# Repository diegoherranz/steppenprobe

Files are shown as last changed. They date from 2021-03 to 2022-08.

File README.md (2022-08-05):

# Steppenprobe
Open Source Hardware JTAG/SWD/UART/SWO interface board

https://github.com/diegoherranz/steppenprobe

## Basic specs:

- Open Source Hardware and designed in [KiCad](https://kicad.org).
- [FT2232H](https://ftdichip.com/products/ft2232hl)-based
- Simultaneous operation of JTAG/SWD and UART/SWO.
- STDC14 connector: standard Arm Cortex debug connector (1.27 mm pitch) with extra pins for UART. JTAG/SWD and UART on a single connector while being compatible with the standard Arm Cortex debug connector (middle 10 pins).
- USB powered: no power supply needed.
- USB type-C receptacle: more convenient (reversible) and future-proof (it should be the most common connector during the next few years).
- OpenOCD compatible, supported from version 0.11.0 (older versions can be used by adapting this [config file](https://sourceforge.net/p/openocd/code/ci/master/tree/tcl/interface/ftdi/steppenprobe.cfg) to the old sintax).
- JTAG or SWD use without any jumper or switch operation required (configured from OpenOCD).
- Switch-selectable UART RX or SWO operation.
- Signals also available on 2.54 mm pin header to work with any custom pinout.
- 4 GPIO.
- System Reset tactile switch.
- I/O buffers for protection and to be able to use a wide voltage range (1.65 V to 5.5 V).
- Descriptive LED indicators.

## Schematic PDF, Gerbers and other generated files:
See [releases](https://github.com/diegoherranz/steppenprobe/releases).

## FTDI channels

The FT2232H has 2 independent channels. In this board:

- Channel A: Used for JTAG or SWD (MPSSE mode) + GPIOs
- Channel B: Used as UART. TX+RX or TX+SWO depending on the position of the physical switch.

After enumeration, both channels will default to UART mode, so on a Linux system they will show up as `/dev/ttyUSB0` and `/dev/ttyUSB1`. When channel A gets reconfigured to MPSSE mode (e.g. when using OpenOCD with it), then `/dev/ttyUSB0` will disappear and channel B will remain as `/dev/ttyUSB1`.

## 3D renders

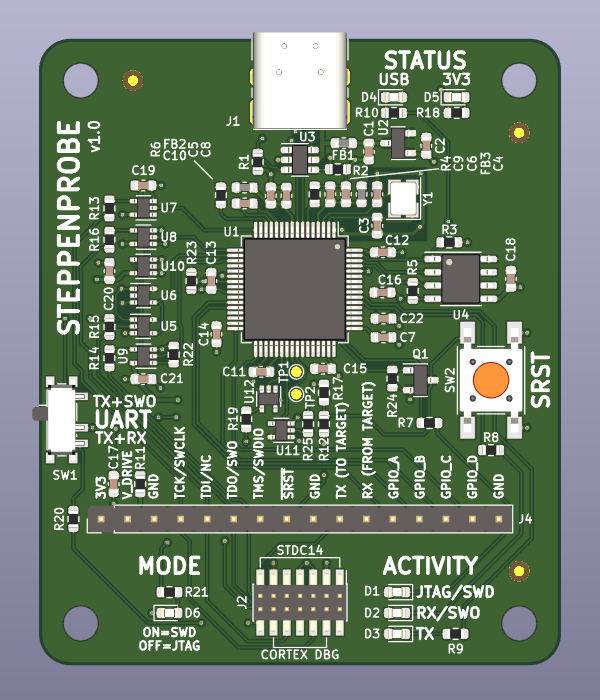
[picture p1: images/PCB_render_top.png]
PCB top view
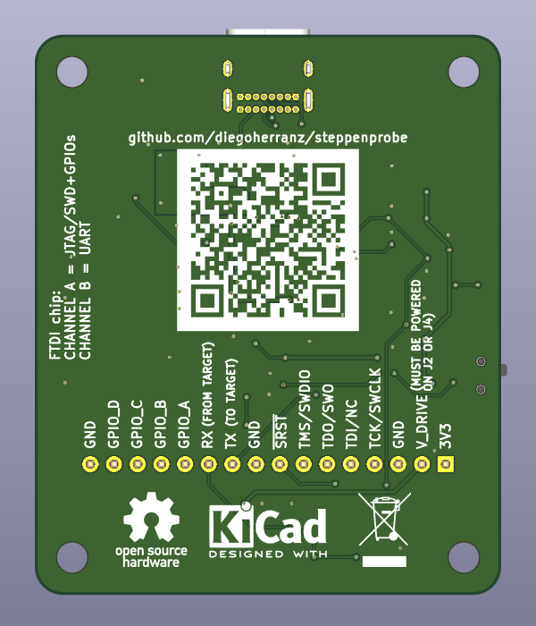
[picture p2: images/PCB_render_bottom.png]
PCB bottom view
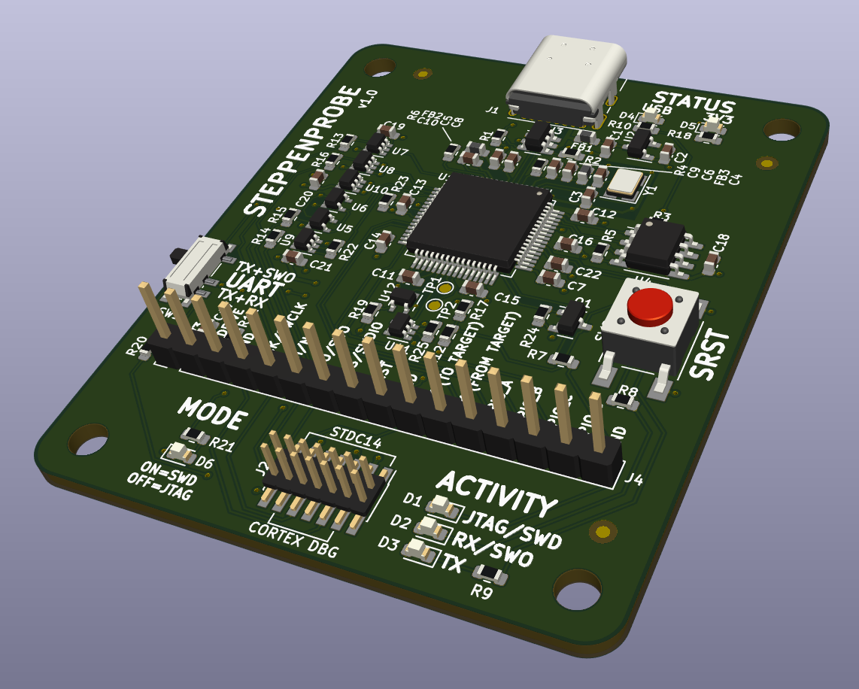
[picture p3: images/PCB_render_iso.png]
PCB isometric view
  

## Options for J2 connector (1.27 mm pitch header)
You can solder a 10-way or 14-way header depending on what suits you best:
 - 10-way header: [FTSH-105-01-F-DV-K](https://www.samtec.com/products/ftsh-105-01-f-dv-k) or equivalent. Use the central 10 pads in this case. JTAG, SWD, SWO and RESET (Arm Cortex debug connector standard).
 - 14-way header: [FTSH-107-01-F-DV-K](https://www.samtec.com/products/ftsh-107-01-f-dv-k) or equivalent. Compared to the 10 pin option, it adds UART TX and RX (STDC14 standard). This can still connect to targets with a 10-way header by using a 14-way to 10-way cable.

## OpenOCD example commands

### Flashing
Flashing [NuttX](https://nuttx.apache.org) to a [Blue Pill](https://stm32-base.org/boards/STM32F103C8T6-Blue-Pill.html) using JTAG:

```
openocd -f interface/ftdi/steppenprobe.cfg -f target/stm32f1x.cfg -c "program nuttx.bin 0x08000000 verify reset exit"
```

Same but using SWD:

```
openocd -f interface/ftdi/steppenprobe.cfg -c "transport select swd" -f target/stm32f1x.cfg -c "program nuttx.bin 0x08000000 verify reset exit"
```
All these examples use the default reset signals configuration. You may need to adjust it for your target board to work or even if it works, you may want to define it explicitely. See the [Reset Configuration chapter](http://openocd.org/doc-release/html/Reset-Configuration.html) of the OpenOCD documentation for more details.

You can do so directly on the OpenOCD command:

```
openocd -f interface/ftdi/steppenprobe.cfg -c "reset_config srst_only" -f target/stm32f1x.cfg -c "program nuttx.bin 0x08000000 verify reset exit"
```

or defining your board config file (your_board.cfg) which may look like this:

```
reset_config srst_only
source [find target/stm32f4x.cfg]
```

And then you do:

```
openocd -f interface/ftdi/steppenprobe.cfg -f your_board.cfg -c "program nuttx.bin 0x08000000 verify reset exit"
```

### Debugging
Debugging example for an STM32F4 target.

Start OpenOCD:
- JTAG: `openocd -f interface/ftdi/steppenprobe.cfg -f target/stm32f4x.cfg`
- SWD: `openocd -f interface/ftdi/steppenprobe.cfg -c "transport select swd" -f target/stm32f4x.cfg
`

On a different terminal:
```
$ gdb-multiarch your_code.elf # or gcc-arm-none-eabi depending on your system.

# Attach to OpenOCD
(gdb) target extended-remote localhost:3333

# Reset the boad
(gdb) monitor reset halt

# Load the code to flash
(gdb) load

# Start running
continue
```
Then use GDB as normal: see https://www.gnu.org/software/gdb/documentation/

### Debugging + SWO

Start OpenOCD in SWD mode and use the `tpiu config` command. Also, the UART switch should be in the "TX+SWO" position.

```
openocd -f interface/ftdi/steppenprobe.cfg -c "transport select swd" -f target/stm32f4x.cfg -c "tpiu config external uart off 168000000 115200"
```

The `tpiu config` command configures the ARM ITM module and the SWO output. In the command above, `16800000` represents the TRACECLKIN frequency (usually the same as HCLK), and `115200` is the frequency/baurate of the SWO line. Adjust both as desired. See the [OpenOCD documentation](http://openocd.org/doc-release/html/Architecture-and-Core-Commands.html#ARMv7_002dM-specific-commands
) for more info.

If the selected SWO frequency can't be achieved, OpenOCD will output a message like:

> Info : Can not obtain 115200 trace port frequency from 168000000 TRACECLKIN frequency, using 115147 instead

In this case, the frequency achieved is close enough, but pay attention in case it wasn't.

Then, on another terminal:
```
# configure the serial port speed
stty -F /dev/ttyUSB1 115200

# start the ITM decoder
./itmdump -f /dev/ttyUSB1 -d1 
```

Note: ITM decoder available [here](https://sourceforge.net/p/openocd/code/ci/master/tree/contrib/itmdump.c), just compile by doing `gcc itmdump.c -o itmdump`.

One of the advantages of using the SWO signal is that it can be faster than a standard UART, specially for slow core clock frequencies (see [this nice article](https://blog.japaric.io/itm/) for more info). To benefit from that, we need to use faster SWO frequencies.

The FT2232H is capable or running the UART up to 12 Mbps, but the configuration is more cumbersome for the fastest speeds.

On a recent Linux system, you can go up to 4 Mbps, configuring everything the same way as explained above for 115200 bps. On different OSes, you may not be able to go above 115200 bps or even 38400 bps.

For 4 Mbps:

```
openocd -f interface/ftdi/steppenprobe.cfg -c "transport select swd" -f target/stm32f4x.cfg -c "tpiu config external uart off 168000000 4000000"
```

On another terminal:
```
stty -F /dev/ttyUSB1 4000000
./itmdump -f /dev/ttyUSB1 -d1
```

To use even higher frequencies, up to the maximum of 12 MHz if your setup and cabling allows it, it's necessary to use setserial to alias 38400 bps to a custom divider. The base frequency of the FT2232H is 60 MHz, so for instance, for 12 MHz, the divisor must be set to 5.

```
openocd -f interface/ftdi/steppenprobe.cfg -c "transport select swd" -f target/stm32f4x.cfg -c "tpiu config external uart off 168000000 12000000"
```

On a different terminal:
```
setserial /dev/ttyUSB1 spd_cust divisor 5
stty -F /dev/ttyUSB1 38400
./itmdump -f /dev/ttyUSB1 -d1
```

### GPIO usage
There are 4 GPIOs available: GPIO_A to GPIO_D. By default they are High-Impedance (Z).

They can be set through OpenOCD by using `ftdi_set_signal name 0|1|z`. For example:
```
ftdi_set_signal GPIO_B 1
```

And similarly, they can be read using `ftdi_get_signal name`.

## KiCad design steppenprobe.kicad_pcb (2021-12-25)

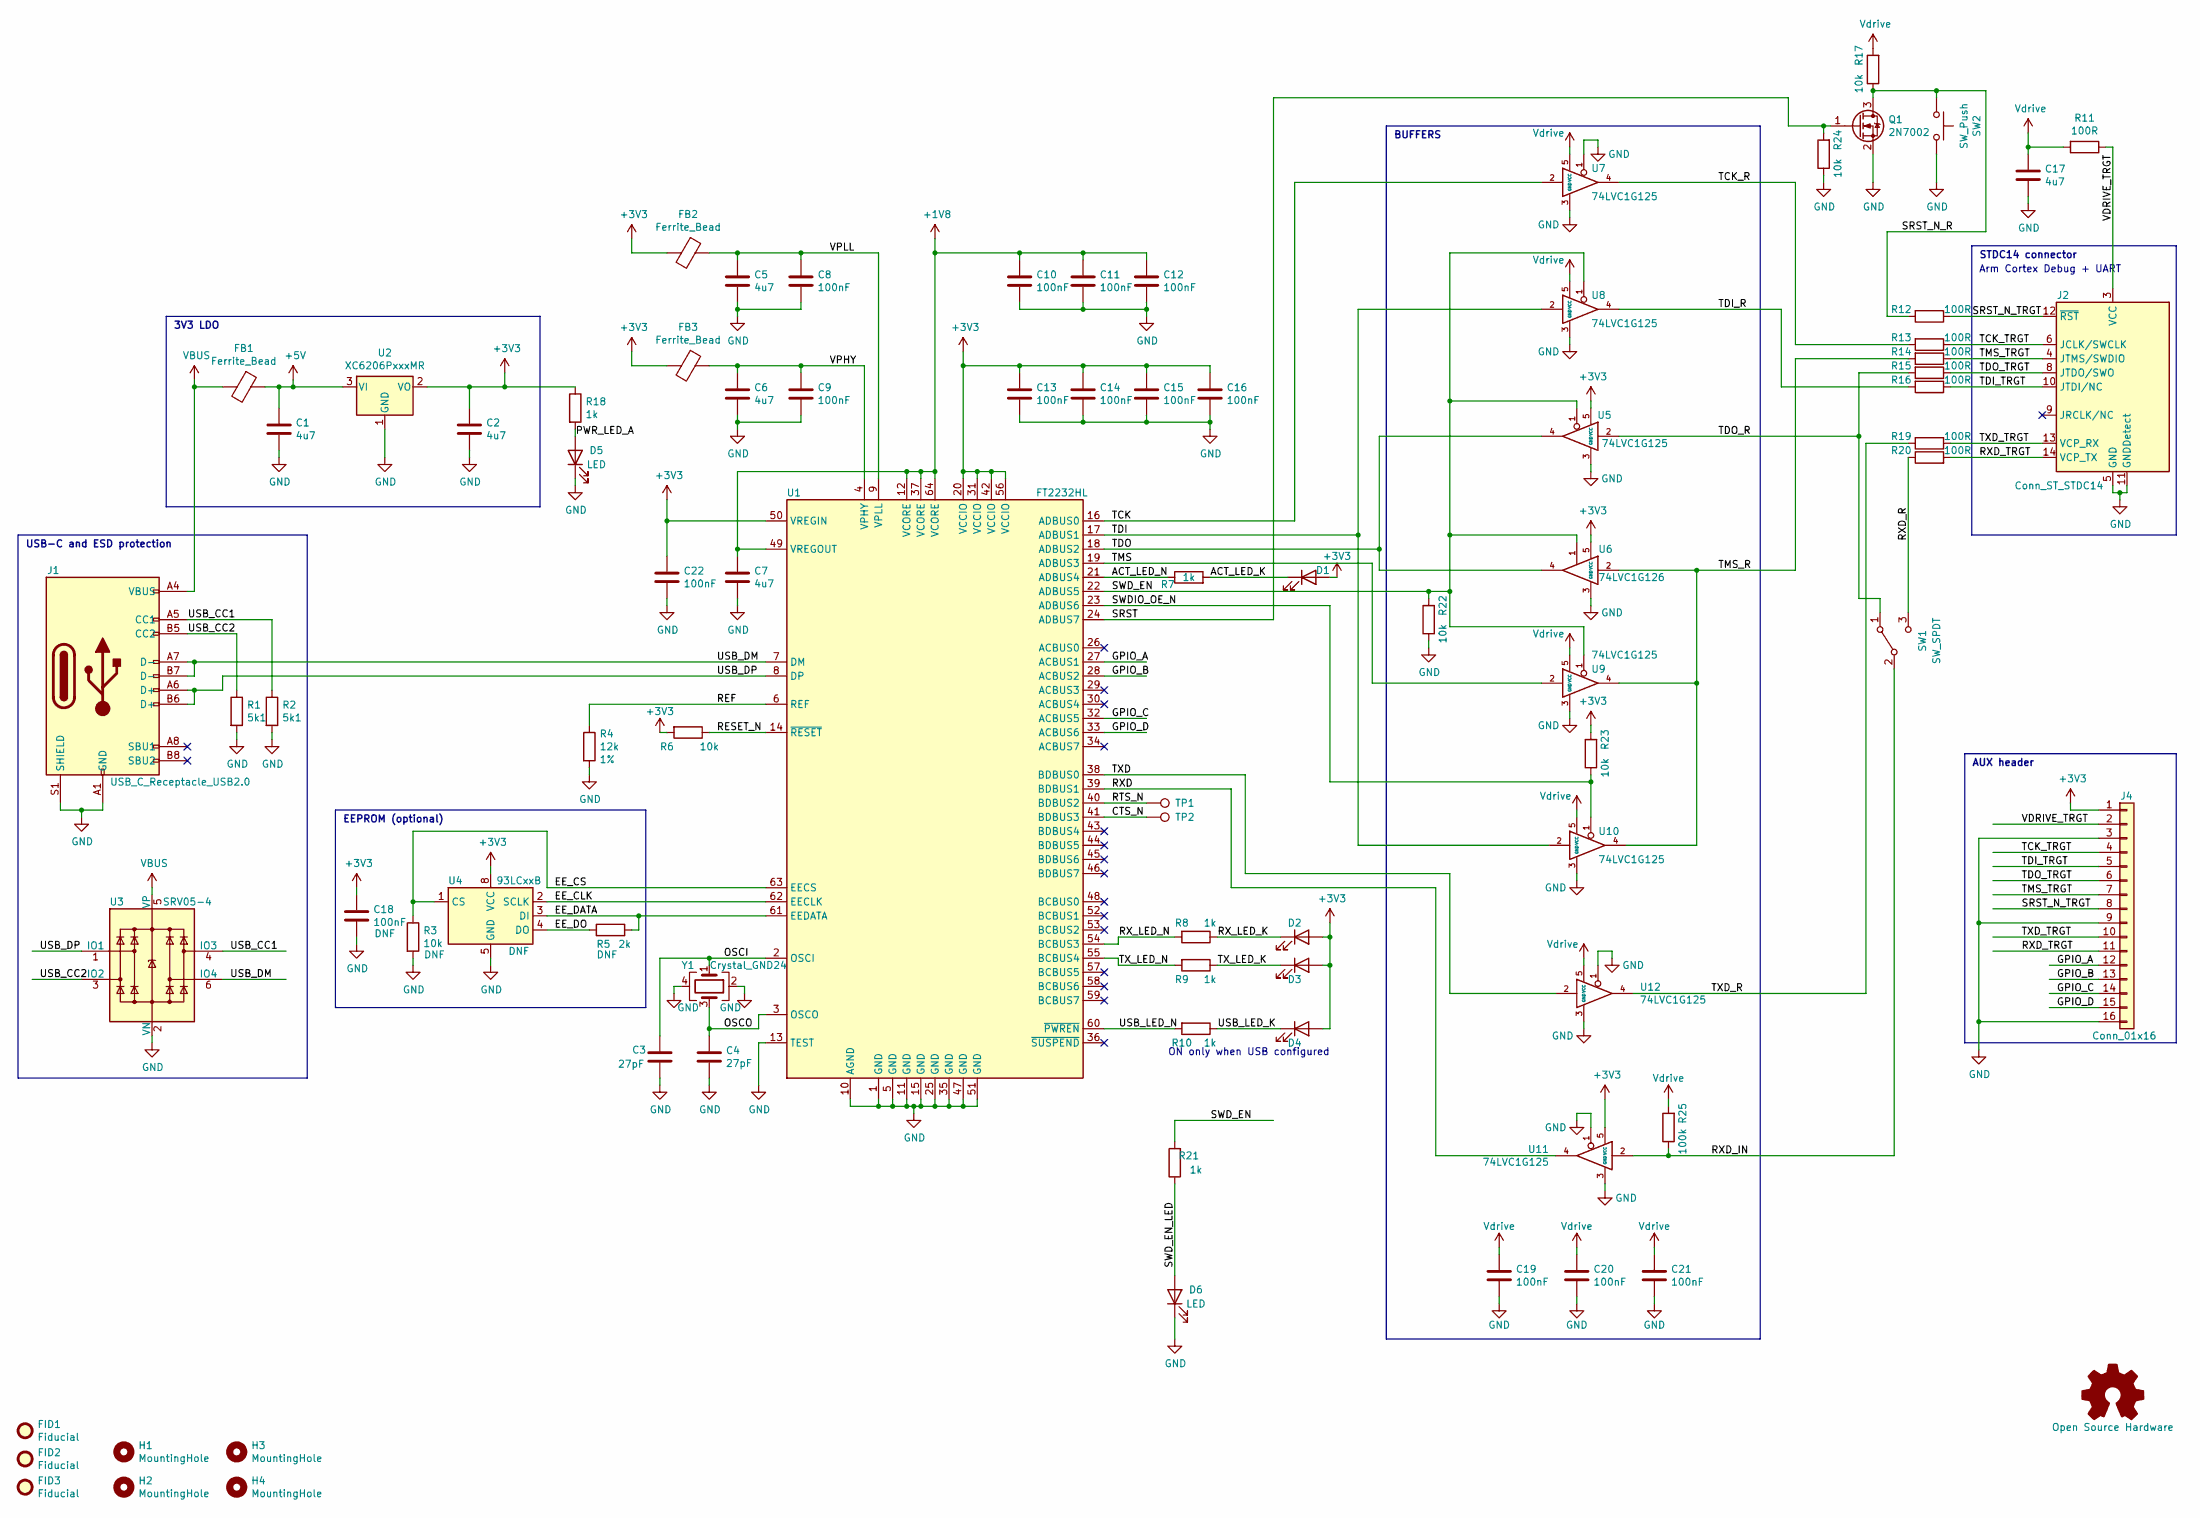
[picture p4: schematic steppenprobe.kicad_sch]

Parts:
C1, C2, C5, C6, C7, C17: 4u7; C_0603_1608Metric; Tolerance 10%; MPN CL10A475KO8NNNC; LCSC_PN C19666
C3, C4: 27pF; C_0603_1608Metric; Tolerance 5%; MPN C0603C270J5GAC; LCSC_PN C1656
C8, C9, C10, C11, C12, C13, C14, C15, C16, C19, C20, C21, C22: 100nF; C_0603_1608Metric; Tolerance 10%; MPN CC0603KRX7R9BB104; LCSC_PN C14663
C18: 100nF; C_0603_1608Metric
D1, D2, D3, D4, D5, D6: LED; LED_0603_1608Metric; MPN 19-217/GHC-YR1S2/3T; LCSC_PN C72043
FB1, FB2, FB3: Ferrite_Bead; L_0603_1608Metric; MPN2 BKP1608HS121-T; LCSC_PN C85831
FID1, FID2, FID3: Fiducial; Fiducial_1mm_Mask2mm
H1, H2, H3, H4: MountingHole; MountingHole_3.2mm_M3
J1: USB_C_Receptacle_USB2.0; USB_C_Receptacle_GCT_USB4085; MPN USB4085-GF-A
J2: Conn_ST_STDC14; PinHeader_2x07_P1.27mm_Vertical_SMD; MPN FTSH-107-01-F-DV-K (if 14-way)
J4: Conn_01x16; PinHeader_1x16_P2.54mm_Vertical; MPN M20-9991645
LOGO1: Open Source Hardware; OSHW-Logo_7.5x8mm_SilkScreen
Q1: 2N7002; SOT-23; MPN 2N7002-7-F; LCSC_PN C8545
R1, R2: 5k1; R_0603_1608Metric; Tolerance 5%; LCSC_PN C23186
R3: 10k; R_0603_1608Metric
R4: 12k; R_0603_1608Metric; Tolerance 1%; LCSC_PN C22790
R5: 2k; R_0603_1608Metric
R6, R17, R22, R23, R24: 10k; R_0603_1608Metric; Tolerance 5%; LCSC_PN C25804
R7, R8, R9, R10, R18, R21: 1k; R_0603_1608Metric; Tolerance 5%; LCSC_PN C21190
R11, R12, R13, R14, R15, R16, R19, R20: 100R; R_0603_1608Metric; Tolerance 5%; LCSC_PN C22775
R25: 100k; R_0603_1608Metric; Tolerance 5%; LCSC_PN C25803
SW1: SW_SPDT; SW_SPDT_PCM12; MPN EG1215AA
SW2: SW_Push; SW_Push_1P1T_NO_E-Switch_TL3301NxxxxxG; MPN PTS645SK43SMTR92 LFS
TP1, TP2: TestPoint; TestPoint_Pad_D1.0mm
U1: FT2232HL; LQFP-64_10x10mm_P0.5mm; MPN FT2232HL; LCSC_PN C27882
U2: XC6206PxxxMR; SOT-23; MPN XC6206P332MR; LCSC_PN C5446
U3: SRV05-4; SOT-23-6; MPN2 SRV05-4-P-T7; LCSC_PN C85364
U4: 93LCxxB; SOIC-8_3.9x4.9mm_P1.27mm
U5, U7, U8, U9, U10, U11, U12: 74LVC1G125; SOT-353_SC-70-5; MPN 74LVC1G125GW,125; LCSC_PN C12519
U6: 74LVC1G126; SOT-353_SC-70-5; MPN 74LVC1G126GW,125; LCSC_PN C55052
Y1: Crystal_GND24; Crystal_SMD_3225-4Pin_3.2x2.5mm; Tolerance 10PPM; MPN ABM8-12.000MHZ-20-B1U-T; LCSC_PN C9002

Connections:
+1V8: C7.1, C10.1, C11.1, C12.1, U1.12 (VCORE), U1.37 (VCORE), U1.49 (VREGOUT), U1.64 (VCORE)
+3V3: C2.1, C13.1, C14.1, C15.1, C16.1, C18.1, C22.1, D1.2 (A), D2.2 (A), D3.2 (A), D4.2 (A), FB2.2, FB3.2, J4.1, R6.2, R18.1, R23.2, U1.20 (VCCIO), U1.31 (VCCIO), U1.42 (VCCIO), U1.50 (VREGIN), U1.56 (VCCIO), U2.2 (VO), U4.8 (VCC), U5.5 (VCC), U6.5 (VCC), U11.5 (VCC)
+5V: C1.1, FB1.1, U2.3 (VI)
/ACT_LED_K: D1.1 (K), R7.2
/ACT_LED_N: R7.1, U1.21 (ADBUS4)
/CTS_N: TP2.1, U1.41 (BDBUS3)
/EE_CLK: U1.62 (EECLK), U4.2 (SCLK)
/EE_CS: R3.1, U1.63 (EECS), U4.1 (CS)
/EE_DATA: R5.2, U1.61 (EEDATA), U4.3 (DI)
/EE_DO: R5.1, U4.4 (DO)
/GPIO_A: J4.12, U1.27 (ACBUS1)
/GPIO_B: J4.13, U1.28 (ACBUS2)
/GPIO_C: J4.14, U1.32 (ACBUS5)
/GPIO_D: J4.15, U1.33 (ACBUS6)
/OSCI: C3.1, U1.2 (OSCI), Y1.1
/OSCO: C4.1, U1.3 (OSCO), Y1.3
/PWR_LED_A: D5.2 (A), R18.2
/REF: R4.1, U1.6 (REF)
/RESET_N: R6.1, U1.14 (~RESET)
/RTS_N: TP1.1, U1.40 (BDBUS2)
/RXD: U1.39 (BDBUS1), U11.4
/RXD_IN: R25.1, SW1.2 (B), U11.2
/RXD_R: R20.1, SW1.3 (C)
/RXD_TRGT: J2.14 (VCP_TX), J4.11, R20.2
/RX_LED_K: D2.1 (K), R8.1
/RX_LED_N: R8.2, U1.54 (BCBUS3)
/SRST: Q1.1 (G), R24.2, U1.24 (ADBUS7)
/SRST_N_R: Q1.3 (D), R12.2, R17.1, SW2.1
/SRST_N_TRGT: J2.12 (~RST), J4.8, R12.1
/SWDIO_OE_N: R23.1, U1.23 (ADBUS6), U10.1
/SWD_EN: R21.2, R22.2, U1.22 (ADBUS5), U5.1, U6.1, U8.1, U9.1
/SWD_EN_LED: D6.2 (A), R21.1
/TCK: U1.16 (ADBUS0), U7.2
/TCK_R: R13.2, U7.4
/TCK_TRGT: J2.6 (JCLK/SWCLK), J4.4, R13.1
/TDI: U1.17 (ADBUS1), U8.2, U10.2
/TDI_R: R16.2, U8.4
/TDI_TRGT: J2.10 (JTDI/NC), J4.5, R16.1
/TDO: U1.18 (ADBUS2), U5.4, U6.4
/TDO_R: R15.2, SW1.1 (A), U5.2
/TDO_TRGT: J2.8 (JTDO/SWO), J4.6, R15.1
/TMS: U1.19 (ADBUS3), U9.2
/TMS_R: R14.2, U6.2, U9.4, U10.4
/TMS_TRGT: J2.4 (JTMS/SWDIO), J4.7, R14.1
/TXD: U1.38 (BDBUS0), U12.2
/TXD_R: R19.2, U12.4
/TXD_TRGT: J2.13 (VCP_RX), J4.10, R19.1
/TX_LED_K: D3.1 (K), R9.1
/TX_LED_N: R9.2, U1.55 (BCBUS4)
/USB_CC1: J1.A5 (CC1), R2.1, U3.4 (IO3)
/USB_CC2: J1.B5 (CC2), R1.1, U3.3 (IO2)
/USB_DM: J1.A7 (D-), J1.B7 (D-), U1.7 (DM), U3.6 (IO4)
/USB_DP: J1.A6 (D+), J1.B6 (D+), U1.8 (DP), U3.1 (IO1)
/USB_LED_K: D4.1 (K), R10.1
/USB_LED_N: R10.2, U1.60 (~PWREN)
/VDRIVE_TRGT: J2.3 (VCC), J4.2, R11.1
/VPHY: C6.1, C9.1, FB3.1, U1.4 (VPHY)
/VPLL: C5.1, C8.1, FB2.1, U1.9 (VPLL)
GND: C1.2, C2.2, C3.2, C4.2, C5.2, C6.2, C7.2, C8.2, C9.2, C10.2, C11.2, C12.2, C13.2, C14.2, C15.2, C16.2, C17.2, C18.2, C19.2, C20.2, C21.2, C22.2, D5.1 (K), D6.1 (K), J1.A1 (GND), J1.A12 (GND), J1.B1 (GND), J1.B12 (GND), J1.S1 (SHIELD), J2.5 (GND), J2.7 (GND), J2.11 (GNDDetect), J4.3, J4.9, J4.16, Q1.2 (S), R1.2, R2.2, R3.2, R4.2, R22.1, R24.1, SW2.2, U1.1 (GND), U1.5 (GND), U1.10 (AGND), U1.11 (GND), U1.13 (TEST), U1.15 (GND), U1.25 (GND), U1.35 (GND), U1.47 (GND), U1.51 (GND), U2.1 (GND), U3.2 (VN), U4.5 (GND), U5.3 (GND), U6.3 (GND), U7.1, U7.3 (GND), U8.3 (GND), U9.3 (GND), U10.3 (GND), U11.1, U11.3 (GND), U12.1, U12.3 (GND), Y1.2, Y1.4
VBUS: FB1.2, J1.A4 (VBUS), J1.A9 (VBUS), J1.B4 (VBUS), J1.B9 (VBUS), U3.5 (VP)
Vdrive: C17.1, C19.1, C20.1, C21.1, R11.2, R17.2, R25.2, U7.5 (VCC), U8.5 (VCC), U9.5 (VCC), U10.5 (VCC), U12.5 (VCC)

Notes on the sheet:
EEPROM (optional)
ON only when USB configured
Arm Cortex Debug + UART
3V3 LDO
AUX header
STDC14 connector
USB-C and ESD protection
BUFFERS

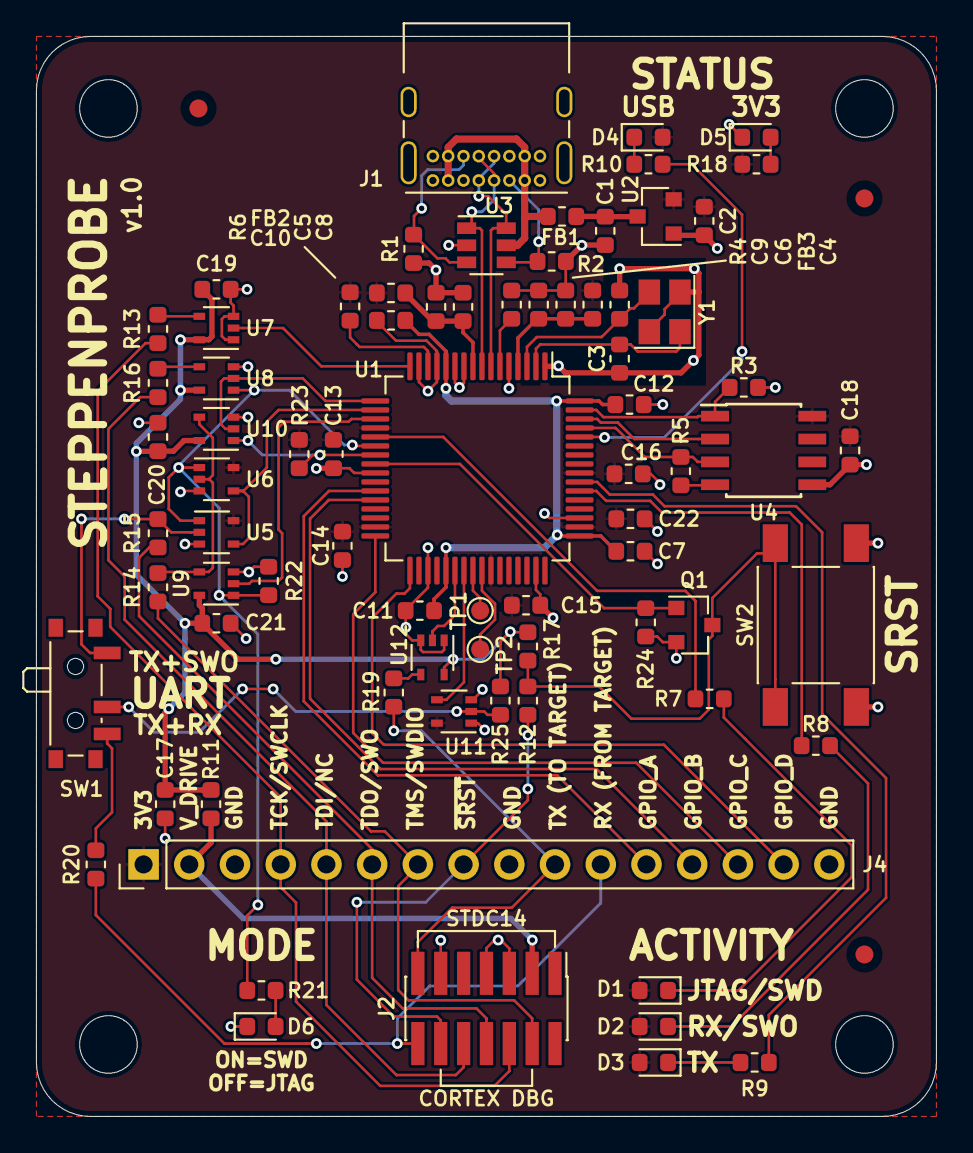
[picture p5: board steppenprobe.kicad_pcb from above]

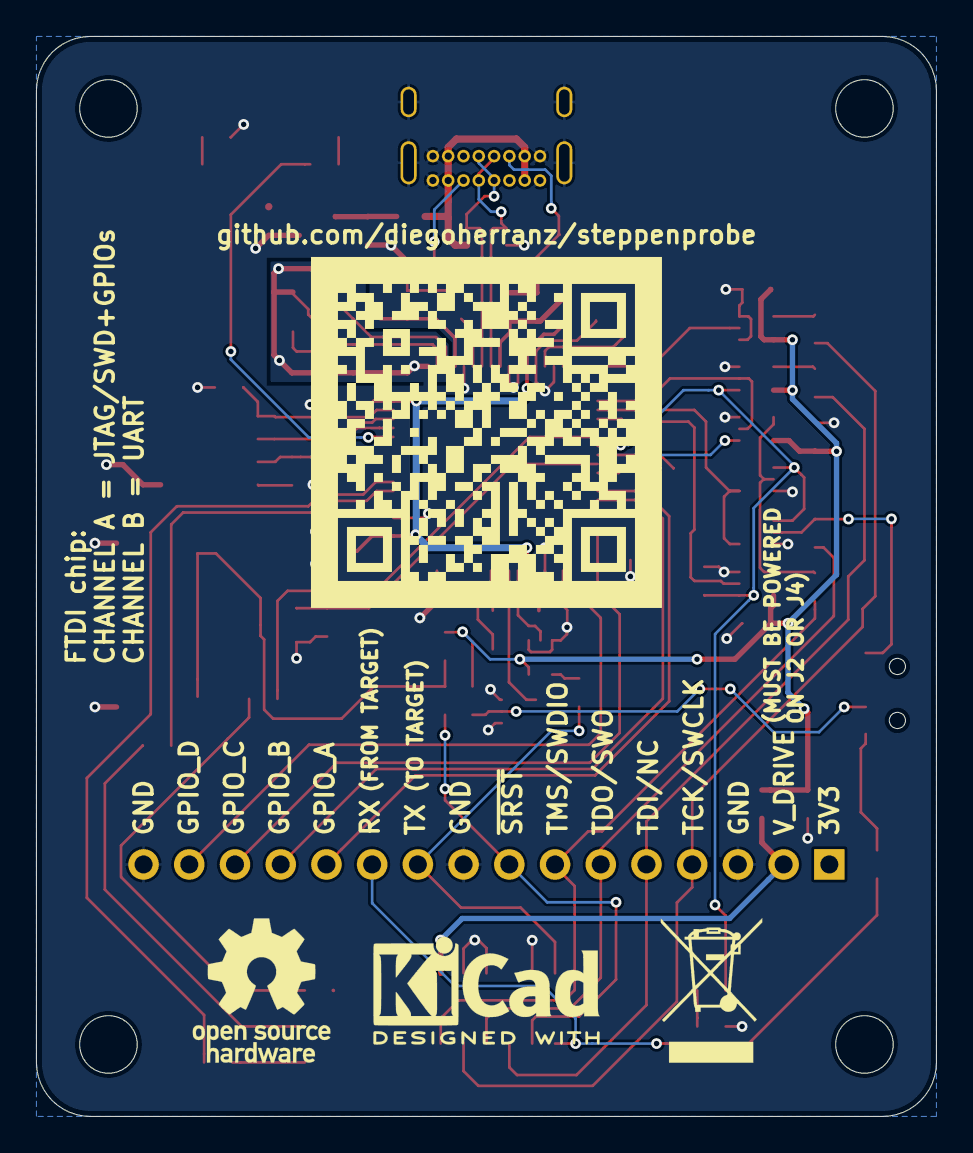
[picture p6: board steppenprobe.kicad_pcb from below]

Board: 2 copper layers, 50.0 x 60.0 mm, 86 parts (2 on the bottom side), 61 nets.

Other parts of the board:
QR*****: qr_steppenprobe_neg

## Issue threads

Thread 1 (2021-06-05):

Unclear how to do SWD + SWO together

philipag, 2021-06-05:
The main readme says that SWD and SWO can work simultaneously but it is unclear how to tell this to openocd?  E.g. how to specify the FT channel to use for SWO?

diegoherranz, 2021-06-13:
I have just done a big update of the README, explaining how to use SWD+SWO.
Hopefully that answers your question. Please re-open this and let me know otherwise.
Thanks!

diegoherranz, 2021-06-13:
By the way, see the section I've added explaining the FTDI channels too.

philipag, 2021-06-13:
Thanks for that Diego.  Yours is a better explanation than any other I have found on the net.  I mistakenly assumed that openocd would be able to directly output the SWO trace output via GDB just like a segger probe can.

Closed 2021-06-13.

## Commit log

2019-08-25 Initial commit
    Schematic basically ready but needs some tidying up
    Layout: approximate placement, tracking pending
    [libre-debugger.kicad_pcb, libre-debugger.sch]
2019-10-08 Progress placement.
    Most components placed.
    Most routing pending.
    [libre-debugger.kicad_pcb, libre-debugger.sch]
2019-10-13 SCH: Replace HC49 crystal by 3225
    Schematic only. Layout update pending.
    [libre-debugger.sch]
2019-10-13 SCH: V_Drive_R for the 2.54mm header too
    [libre-debugger.sch]
2019-10-13 PCB: reshuffle with new smaller crystal
    [libre-debugger.kicad_pcb]
2019-10-27 A few SCH changes:
    - add extra decoupling caps on V_DRIVE
    - Name net SWD_EN_LED
    [libre-debugger.sch]
2019-10-27 Lot of progress on the layout
    Some notes:
    - Top plane/fill is now 3V3
    - Crystal fully routed
    [libre-debugger.kicad_pcb]
2019-10-29 SCH: add cap on VREGIN
    [libre-debugger.sch]
2019-10-30 Layout routed completely. Needs clean-up and tidy-up.
    [libre-debugger.kicad_pcb]
2019-10-31 Some layout tidy-up
    [libre-debugger.kicad_pcb]
2019-10-31 Make MPSSE LED active low
    So that all the activity LEDs have the same orientation.
    [libre-debugger.kicad_pcb, libre-debugger.sch]
2019-11-02 Add pull up on SWDIO_OE and layout clean-up
    - To prevent the buffer to be active when the FTDI pin is High-Z.
    - Some cleanup including silkscreen and Fab
    [libre-debugger.kicad_pcb, libre-debugger.sch]
2019-11-02 Go v0.1
    Test this and only tag v1.0 when all OK
    [libre-debugger.kicad_pcb]
2019-11-03 Add many MPNs and LCSC PNs
    [libre-debugger.sch]
2019-11-03 Replace LDO: MIC5504 -> XC6026
    Available on JLCPCB as Basic Part.
    Many alternative MPNs available for this new footprint, so not an issue.
    [libre-debugger.kicad_pcb, libre-debugger.sch]
2019-11-03 Use 4u7 caps for LDO input and output too
    Minimum size recommended is 1uF input and 1uF output.
    But given capacitance derating vs DC voltage, it is probably
    a good idea to go for a higher value. That reduces the number
    of MPNs too.
    [libre-debugger.kicad_pcb, libre-debugger.sch]
2019-11-04 Add many MPNs including alternatives
    [libre-debugger.sch]
2019-11-16 Layout clean up
    [libre-debugger.kicad_pcb]
2019-11-16 Many layout clean ups including smaller tracks and vias
    Now 0.15mm tracks and 0.6mm/0.3mm vias by default.
    [libre-debugger.kicad_pcb]
2019-11-16 More small layout clean up
    [libre-debugger.kicad_pcb]
2019-11-17 Add KiCad logo + small improvements
    [libre-debugger.kicad_pcb]
2019-11-24 Rename project as Steppenprobe
    [steppenprobe.kicad_pcb, steppenprobe.sch]
2019-11-24 Add QR and new project URL. Finish bottom side silkscreen.
    [steppenprobe.kicad_pcb]
2019-12-01 Add a few more MPNs and tidy-up
    [steppenprobe.sch]
2019-12-01 Add PCB renders to README
2019-12-15 Add pull down resistor to SWD_EN
    I thought that the LED on that net would keep the net low when the
    FTDI chip leaves reset, but the internal pull up is able to pull it
    to ~2.3V. So, external pull down needed.
    [steppenprobe.sch]
2019-12-15 Add pulldown to SRST (also rename from SRST_N)
    [steppenprobe.sch]
2020-01-09 Tidy-up schematic.
    [steppenprobe.sch]
2020-01-12 Swap activity led and reset output. Remap GPIOs. Plus some tidy up.
    - GPIOs only using pins which boot as input (with 75k pull up): GPIO0 was
    driven low on boot which can cause undesired effects. GPI03 booted as
    RXLED# which is an input with a PU on idle but it could togle low if the
    chip receives anything on RX (e.g. noise).
    - MPSSE_LED_N renamed as ACT_LED_N (shorter)
    - GPIO{0..3} renamed as GPIO_{A-D}: so that they are not confused with
    the FTDI numbering.
    [steppenprobe.sch]
2020-02-09 Replace reset switch and layout changes
    - Reset switch SW_Push_1P1T_NO_E-Switch_TL3301NxxxxxG instead of SW_SPST_PTS645.
    The old one is smaller and not compatible (or at least too tight) with many easily sourceable 6mm switches.
    The new footprint should be compatible with many more options including the previous PTS645.
    Some small tweaks were required around it given its slightly bigger size.
    - Version now v1.0
    - GPIO names changed from 0-3 to A-D
    - FTDI channel note made bigger and thicker. Now vertical left of the QR.
    - QR not inverted anymore (some scanners struggled to read it).
    - WEEE symbol added and symbols placed at the south end on the bottom side.
    [steppenprobe.kicad_pcb, steppenprobe.sch]
2020-02-22 Replace FT2232H by FT2232HL
    Old symbol is no longer in the library. It was a common symbol for
    both LQFP and QFN and it is now individual symbols for different
    packages.
    [steppenprobe.kicad_pcb, steppenprobe.sch]
2020-02-23 Move 74xxGxx to a project library
    The symbols in the upstream libraries use hidden power pins which
    doesn't work in this design which needs different power rails on
    different instances.
    So far, a private modifed branch of the libraries was used. But,
    becasue the upstream library won't be fix until KiCad 6 for
    compatibility reasons, a project library has been created which
    makes it easier to share this project.
    [steppenprobe.sch]
2020-04-11 Add pull up resistor to RXD_IN
    To avoid spurious RX when floating.
    Also some small tidy up of silkscreen designators.
    [steppenprobe.kicad_pcb, steppenprobe.sch]
2020-04-11 LED resistors: 470R -> 1k They were too bright. 1k may still be a bit too bright but if the current is reduced further, the LEDs which blink for brief instants, like the JTAG/SWD activity, get harder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
    [steppenprobe.kicad_pcb, steppenprobe.sch]
2020-04-12 Zones re-filled
    [steppenprobe.kicad_pcb]
2020-04-12 Small silkscreen tweaks
    - Lines drawn around J2 now to the centre of the pads
    - "STEPPENPROBE" and "v1.0" moved slightly south
    [steppenprobe.kicad_pcb]
2020-04-12 Tolerance and Type information added for BOM
    [steppenprobe.sch]
2020-04-12 Add 10-way Samtec connector as alternative to the 14-way.
    [steppenprobe.sch]
2020-04-12 Small schematic tidy-up
    [steppenprobe.sch]
2020-04-12 Add bom.ini: configuration for KiBoM
2020-04-12 Tweak soldermask parameters
    Clearence: 50um
    Minimum width: 100um
    And re-fill zones.
    [steppenprobe.kicad_pcb]
2021-11-09 Update README.md
    https://forum.kicad.info/t/warning-avoid-all-links-to-kicad-pcb-org-use-kicad-org/31521
2021-12-25 Update project to KiCad 6.0.0 format
    It was using the interim 5.99 nightlies
    [steppenprobe.kicad_pcb, steppenprobe.kicad_sch, steppenprobe.sch]
2021-12-25 Some cleanup after converting to KiCad 6.0
    - Dangling tracks within pads
    - SRST track had a clearance violation next to FTDI's pin 48,
    by only a few microns. Touched slightly to fix it.
    [steppenprobe.kicad_pcb]
2024-07-15 Save files with KiCad 8.0.x
    No change done, just open and save using KiCad 8.0.x.
